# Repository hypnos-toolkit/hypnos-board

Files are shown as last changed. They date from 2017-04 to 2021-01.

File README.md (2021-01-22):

# Hypnos Board 

Hypnos is a hardware and software toolkit which facilitates the creation of energy-aware IoT nodes based on widely extended consumer board platforms: Arduino, LinkIt One and Particle, to mention a few.

The present repository contains the circuit schematics of the Hypnos Board and the source code of the firmware for the ATtiny85 integrated on it.

# Repository contents

The following list describes the different files that can be found in the repository:
* Hypnos Board - Schematic ([EAGLE](./HYPNOS_BOARD_SHIELD_V1.sch), [PDF](./HYPNOS_BOARD_SHIELD_V1.pdf))
* Hypnos Board - Arduino Shield PCB layout ([EAGLE](./HYPNOS_BOARD_SHIELD_V1.brd), [PDF](./HYPNOS_BOARD_SHIELD_V1.brd.pdf))
* ATtiny85 firmware ([INO](./board-microcontroller/microcontroller-firmware.ino))

# Compatibility

The board has been successfully tested on the following microcontroller boards:
* Arduino UNO R3
* SeeedStudio LinkIt One
* Particle Photon (via a Shield-Shield adapter)

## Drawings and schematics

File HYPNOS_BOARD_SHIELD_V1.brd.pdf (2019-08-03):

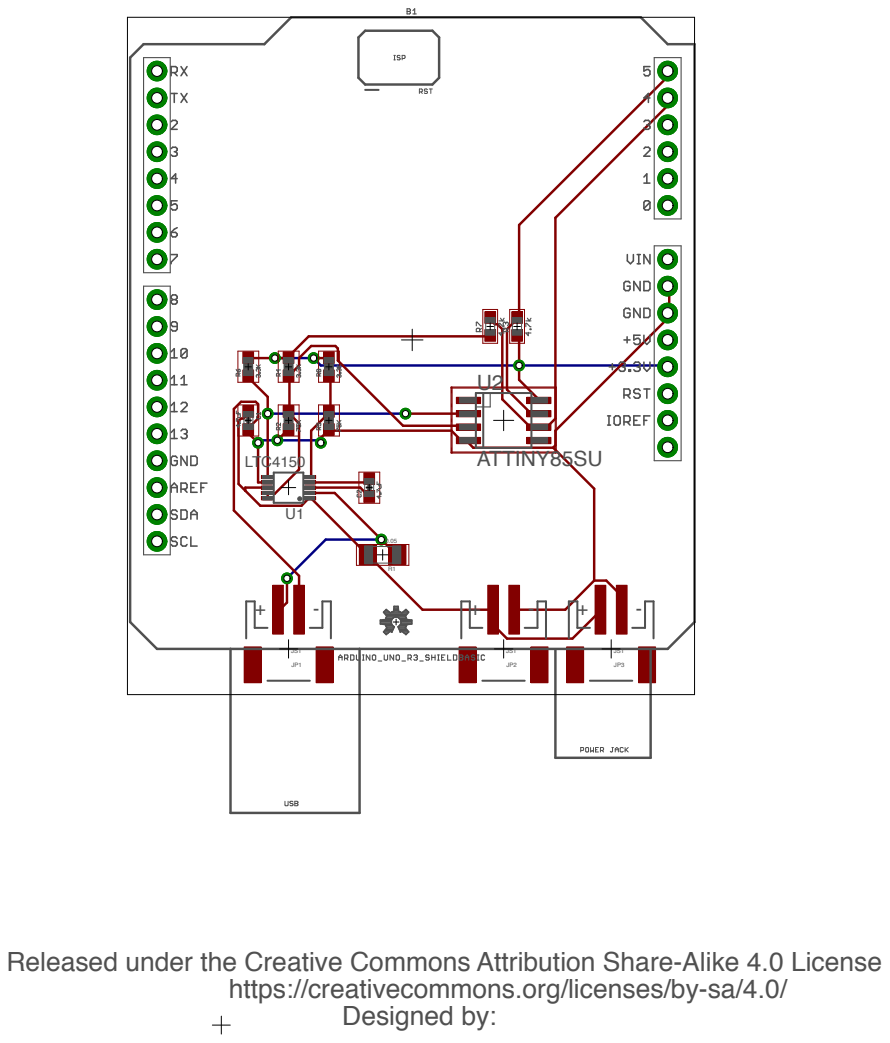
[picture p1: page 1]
Designed by:; JST; LTC4150; ATTINY85SU

Released under the Creative Commons Attribution Share-Alike 4.0 License

https://creativecommons.org/licenses/by-sa/4.0/

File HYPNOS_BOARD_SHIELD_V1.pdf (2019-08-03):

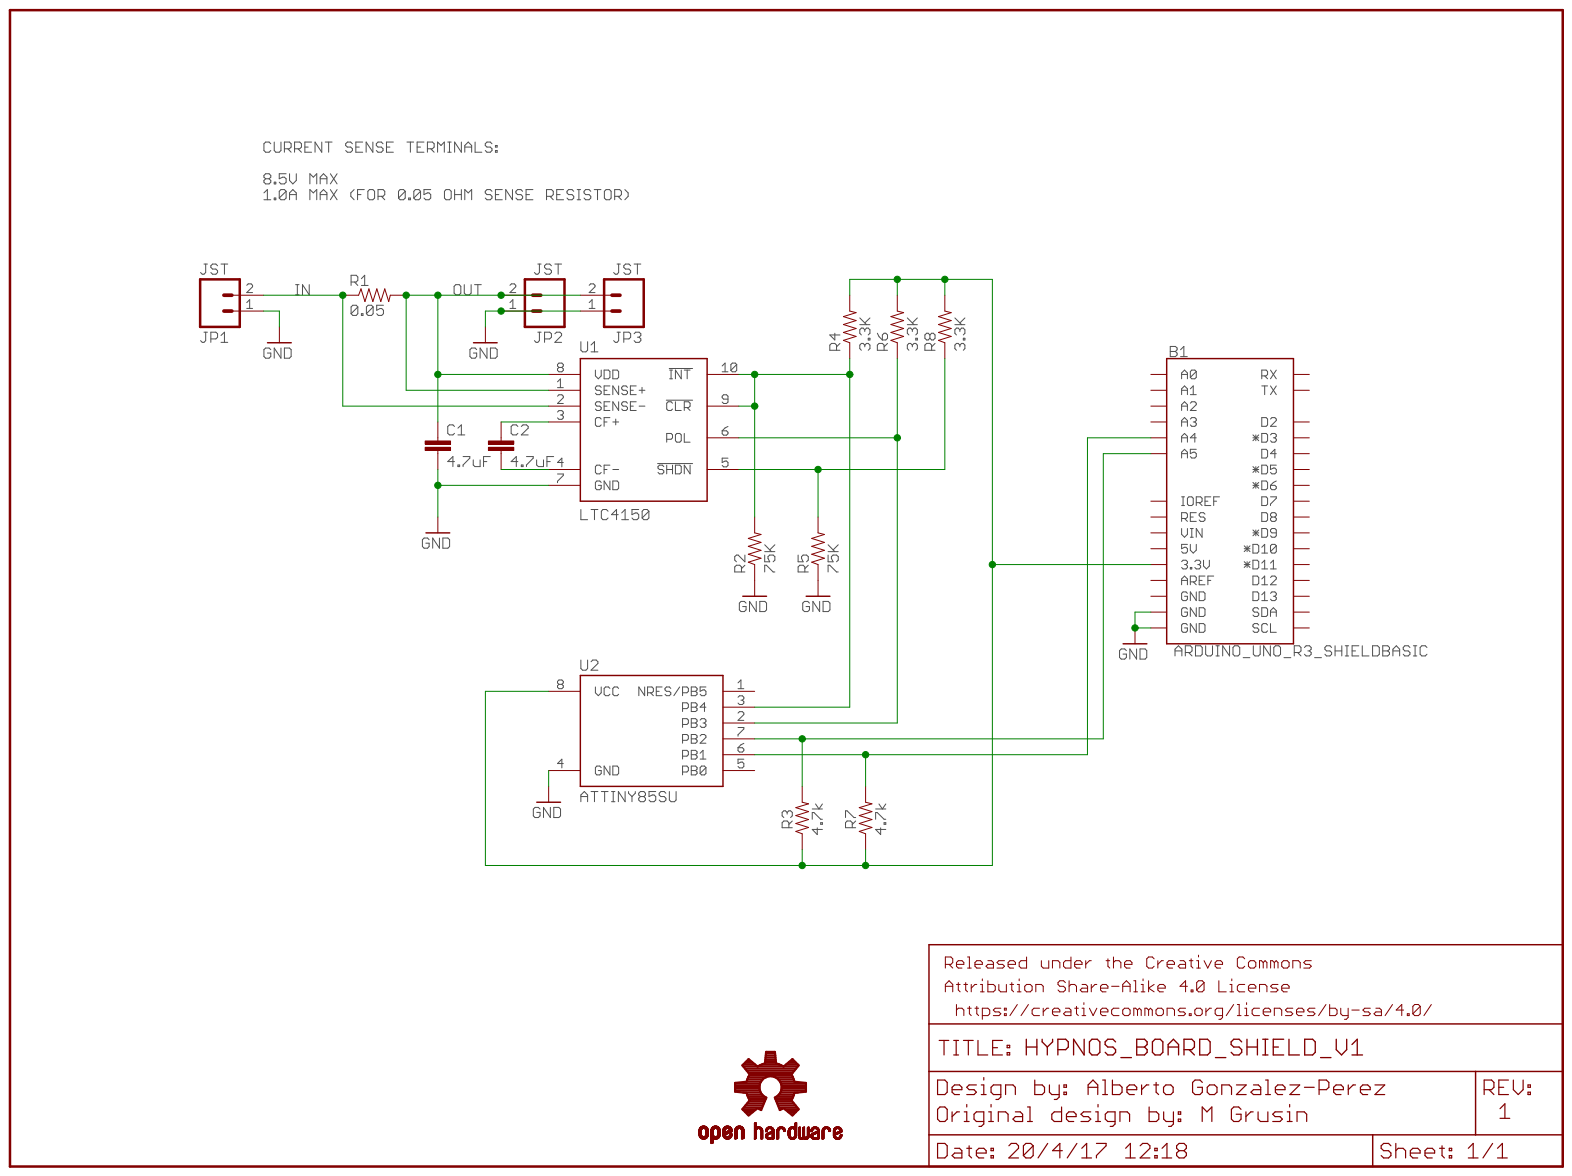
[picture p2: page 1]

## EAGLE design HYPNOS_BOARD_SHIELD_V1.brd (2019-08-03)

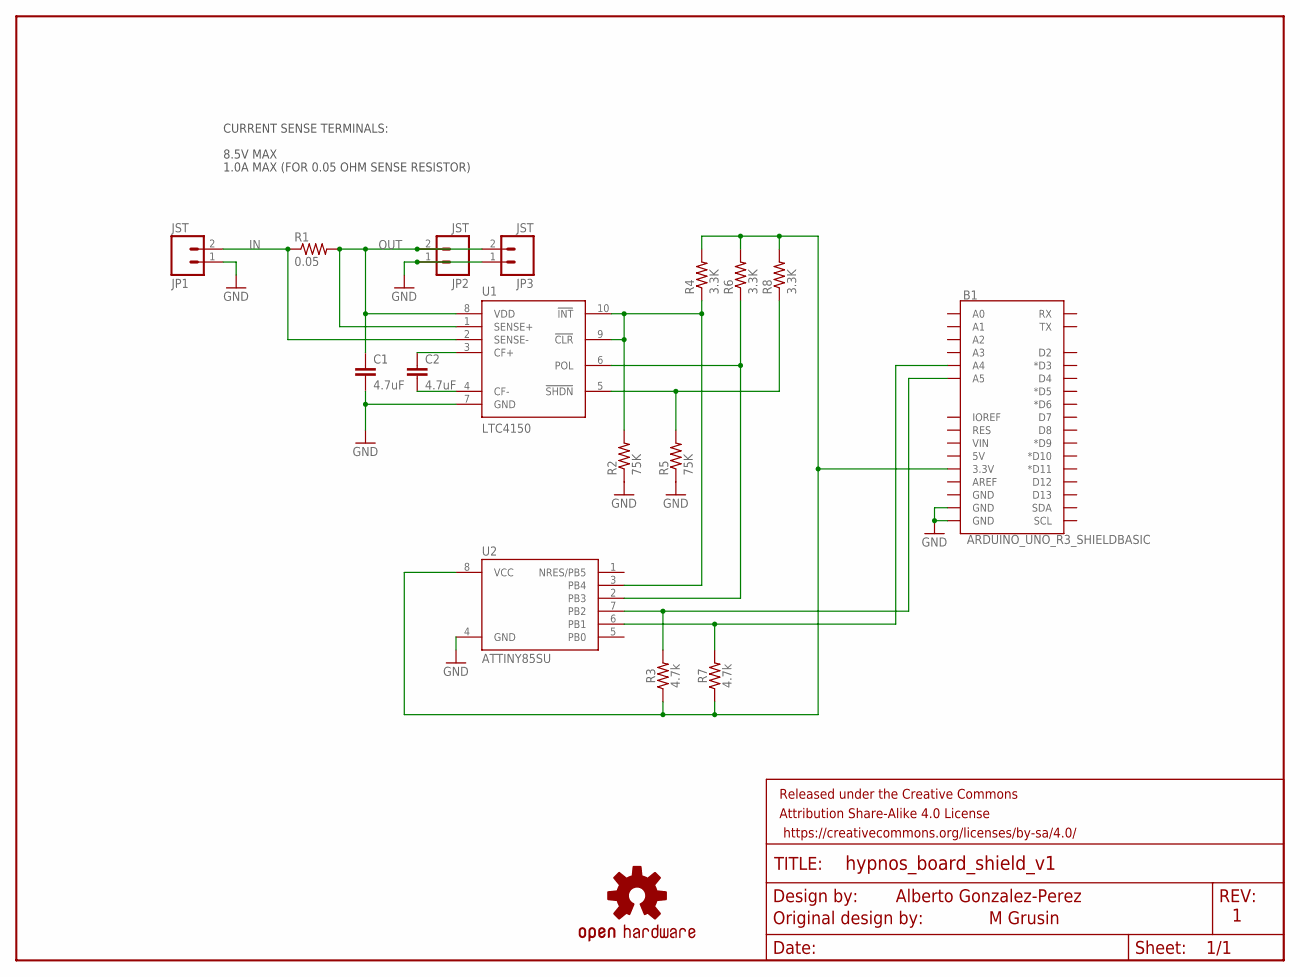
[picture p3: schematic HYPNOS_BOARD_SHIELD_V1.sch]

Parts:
B1: ARDUINO_UNO_R3_SHIELDBASIC; UNO_R3_SHIELD
C1, C2: 4.7uF; 0603-CAP
FRAME1: FRAME-LETTER; CREATIVE_COMMONS
JP1, JP2, JP3: JST; JST-2-SMD
LOGO1: OSHW-LOGOS; OSHW-LOGO-S
R1: 0.05; 1206
R2, R5: 75K; 0603-RES
R3, R7: 4.7k; 0603
R4, R6, R8: 3.3K; 0603-RES
U1: LTC4150; MSOP10
U2: ATTINY85SU; ATTINY85

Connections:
3V3: B1.3.3V, R3.1, R4.2, R6.2, R7.1, R8.2, U2.8 (VCC)
!INT!: R2.2, R4.1, U1.9 (!CLR!), U1.10 (!INT!), U2.3 (PB4)
!SHDN!: R5.2, R8.1, U1.5 (!SHDN!)
GND: B1.GND@0 (GND), B1.GND@1 (GND), C1.2, JP1.1 (2), JP2.1 (2), JP3.1 (2), R2.1, R5.1, U1.7 (GND), U2.4 (GND)
IN: JP1.2 (1), R1.1, U1.2 (SENSE-)
unnamed: B1.A5, R3.2, U2.7 (PB2)
unnamed: C2.1, U1.3 (CF+)
unnamed: C2.2, U1.4 (CF-)
OUT: C1.1, JP2.2 (1), JP3.2 (1), R1.2, U1.1 (SENSE+), U1.8 (VDD)
POL: R6.1, U1.6 (POL), U2.2 (PB3)
SDA: B1.A4, R7.2, U2.6 (PB1)

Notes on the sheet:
M Grusin
CURRENT SENSE TERMINALS:
1.0A MAX (FOR 0.05 OHM SENSE RESISTOR)
8.5V MAX
Original design by:
Alberto Gonzalez-Perez

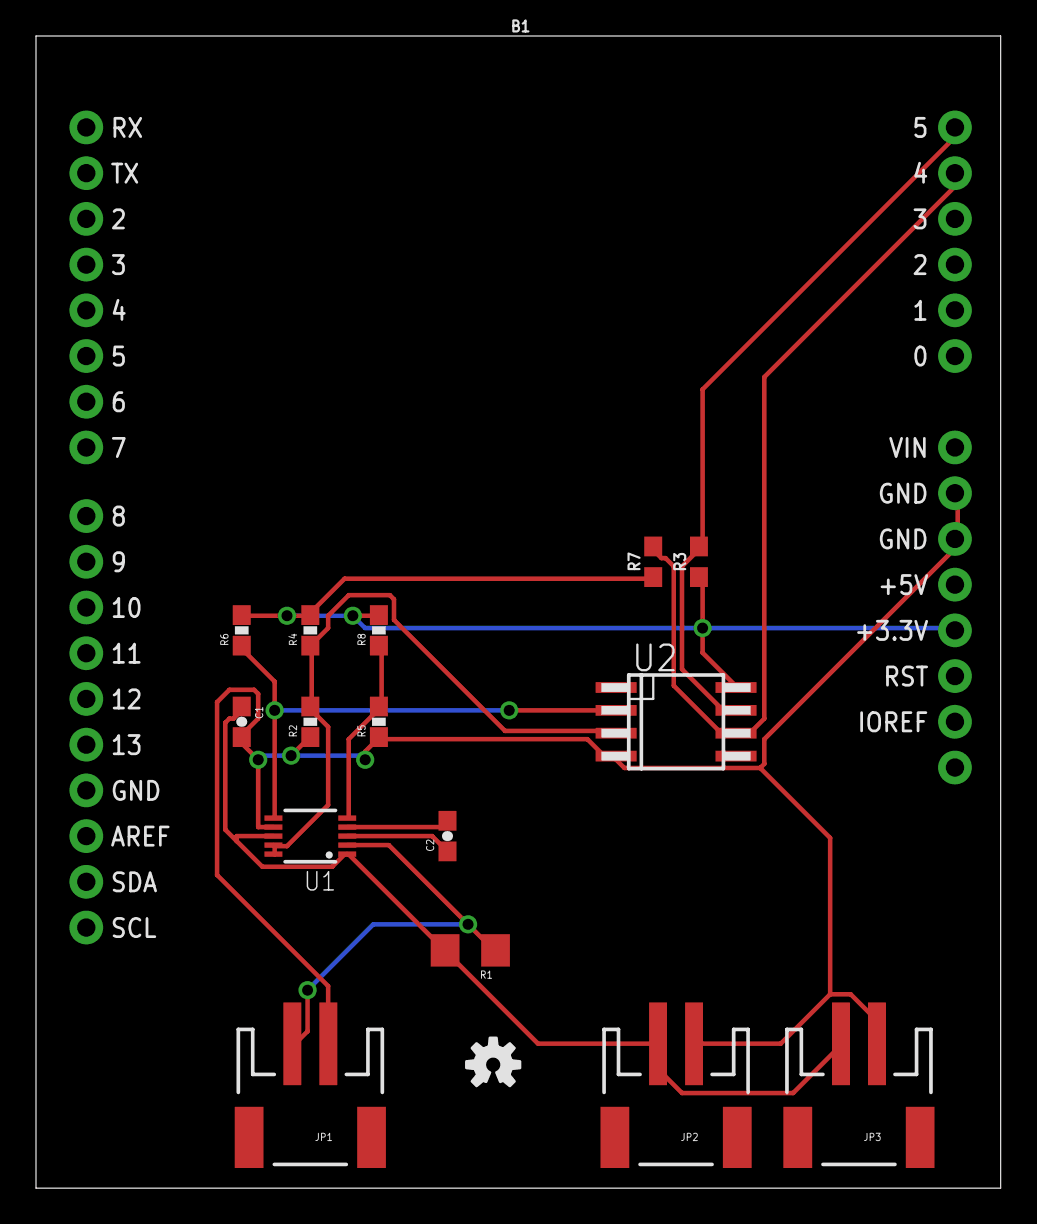
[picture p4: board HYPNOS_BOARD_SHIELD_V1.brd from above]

Board: 2 copper layers, 53.6 x 64.0 mm, 18 parts (0 on the bottom side), 11 nets.

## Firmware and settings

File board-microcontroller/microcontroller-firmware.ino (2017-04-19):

/**
 * Author: Alberto Gonzalez Perez
 *
 * The following code works on an Attiny85 microcontroller (uC), it
 * hadn't been tested in other uCs.
 *
 * This code listens to the interrupts triggered by the LTC4150 IC
 * and reads from the polarity pin of the same circuit to update
 * the current number of times that the interruption has been
 * triggered to charge or discharge system's battery.
 *
 * An interruption triggered while the POS pin is in LOW state
 * means a discharge status. Meanwhile a HIGH state means a charge
 * status.
 */


/**
 * Pin notes by Suovula, see also http://hlt.media.mit.edu/?p=1229
 *
 * DIP and SOIC have same pinout, however the SOIC chips are much cheaper, especially if you buy more than 5 at a time
 * For nice breakout boards see https://github.com/rambo/attiny_boards
 *
 * Basically the arduino pin numbers map directly to the PORTB bit numbers.
 *
 // I2C
 arduino pin 0 = not(OC1A) = PORTB <- _BV(0) = SOIC pin 5 (I2C SDA, PWM)
 arduino pin 2 =           = PORTB <- _BV(2) = SOIC pin 7 (I2C SCL, Analog 1)
 // Timer1 -> PWM
 arduino pin 1 =     OC1A  = PORTB <- _BV(1) = SOIC pin 6 (PWM)
 arduino pin 3 = not(OC1B) = PORTB <- _BV(3) = SOIC pin 2 (Analog 3)
 arduino pin 4 =     OC1B  = PORTB <- _BV(4) = SOIC pin 3 (Analog 2)
 */
#define I2C_SLAVE_ADDRESS 0x4 // the 7-bit address
#include <avr/interrupt.h>
#include "TinyWireSlave.h"

#define INT_pin 3
#define POL_pin 4

#define LONG_BYTES 4

volatile boolean fallingFlank = true;

volatile unsigned long chargeTicks = 0L;
volatile byte offset = 0;

/**
 * Each time a request is performed from the master, the uC sends
 * the last number of chargeTicks stored in memory.
 */
void requestEvent()
{
    TinyWireS.send((uint8_t) (chargeTicks >> (LONG_BYTES - offset-1) * 8) & 0xFF);
    offset = (offset + 1) % LONG_BYTES;
}

/**
 * This is called each time an interrupt is triggered, on RISING
 * and FALLING flanks
 */
ISR(PCINT0_vect) {
  
  if (fallingFlank) {
    boolean charging = digitalRead(POL_pin);
    if (charging && chargeTicks > 0) {
      chargeTicks--;
    }
    if (!charging) {
      chargeTicks++;
    }
  }
  fallingFlank = !fallingFlank; // Prepare for the next stage
}

void setup() {

    pinMode(POL_pin, INPUT); // Polarity pin
    pinMode(INT_pin, INPUT); // Interrupt pin
    GIMSK = 0b00100000; // Enable PC interrupts
    PCMSK = 0b00001000; // Enable interrupts on pin 3
    sei();

    TinyWireS.begin(I2C_SLAVE_ADDRESS);
    TinyWireS.onRequest(requestEvent);
}

void loop() {
  
    /**
     * This is the only way we can detect stop condition (http://www.avrfreaks.net/index.php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)
     * it needs to be called in a very tight loop in order not to miss any (REMINDER: Do *not* use delay() anywhere, use tws_delay() instead).
     * It will call the function registered via TinyWireS.onReceive(); if there is data in the buffer on stop.
     */
    TinyWireS_stop_check();
}

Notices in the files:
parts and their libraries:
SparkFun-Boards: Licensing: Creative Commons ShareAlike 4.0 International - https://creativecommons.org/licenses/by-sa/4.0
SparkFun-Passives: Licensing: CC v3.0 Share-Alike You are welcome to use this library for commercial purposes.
